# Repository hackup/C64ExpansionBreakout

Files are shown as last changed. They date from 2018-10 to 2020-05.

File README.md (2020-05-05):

# C64ExpansionBreakout

This is an adapter board for the [expansion port](https://www.c64-wiki.com/wiki/Expansion_Port) of the Commodore 64. It connects the expansion port to a standard 830 pin prototyping breadboard to assist with the development of modules or cartridges. **USE AT YOUR OWN RISK!**

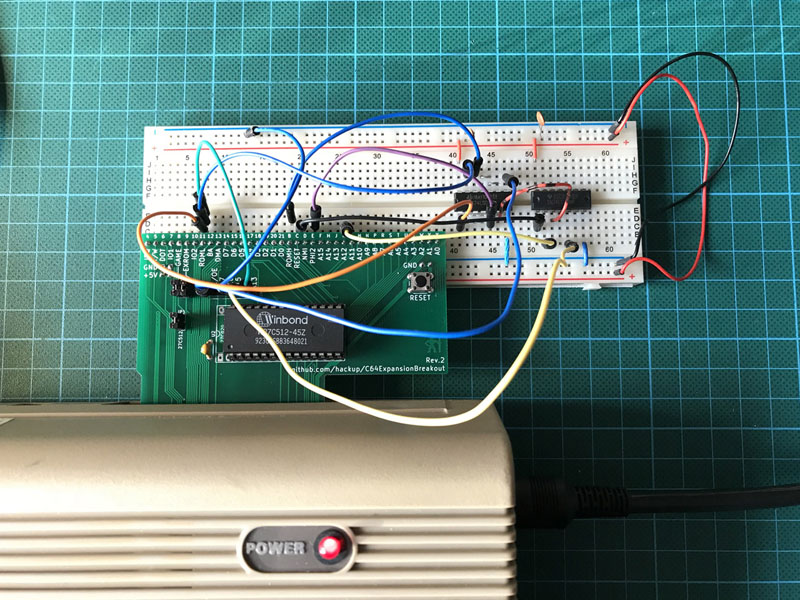
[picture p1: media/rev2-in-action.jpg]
Adapter In Action


### Revision 2
This revision adds an optional on-board slot for either a 27c512 or 27c020 EPROM. The data bus lines D0-D7 and the address bus lines A0-A12 are connected directly to the slot, as are GND and the 5V power rail. The remaining address bus lines of the EPROM and CE/OE are available on J4. Jumper JP1 must be closed if a 27c512 chip is used.

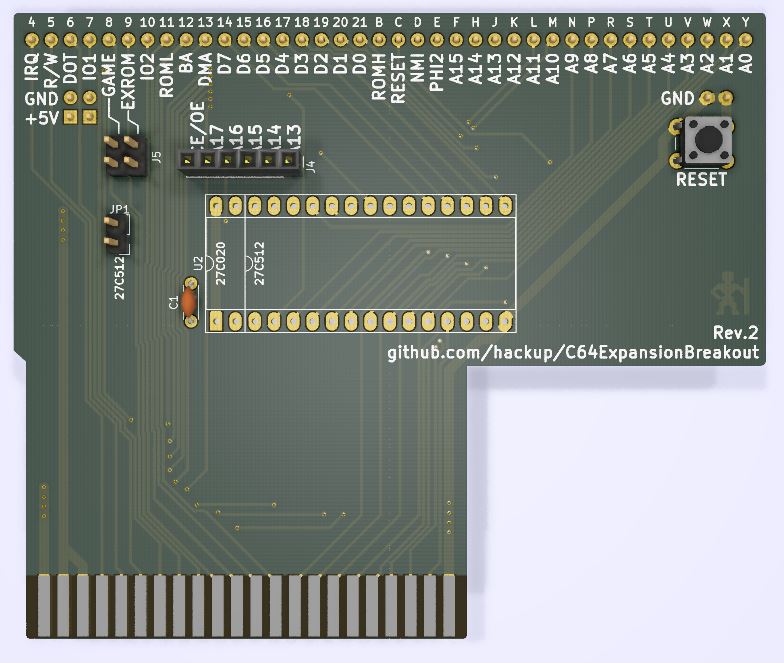
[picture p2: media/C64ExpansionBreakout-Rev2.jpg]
C64ExpansionBreakout Rev. 2


### Revision 1
The first revision directly connects all 38 lines from the expansion port tho the breadboard. 5V and GND are connected to the matching rails on the breadboard. A reset button is added for convenience.

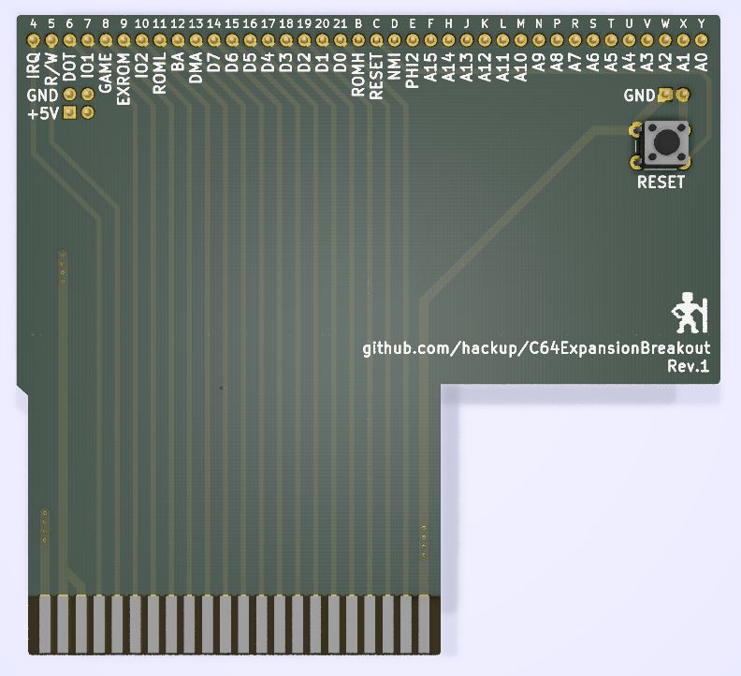
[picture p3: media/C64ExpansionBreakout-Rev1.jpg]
Pi1541io Rev.1


## License


This work is licensed under a
[Creative Commons Attribution-NonCommercial-ShareAlike 4.0 International License](http://creativecommons.org/licenses/by-nc-sa/4.0/).

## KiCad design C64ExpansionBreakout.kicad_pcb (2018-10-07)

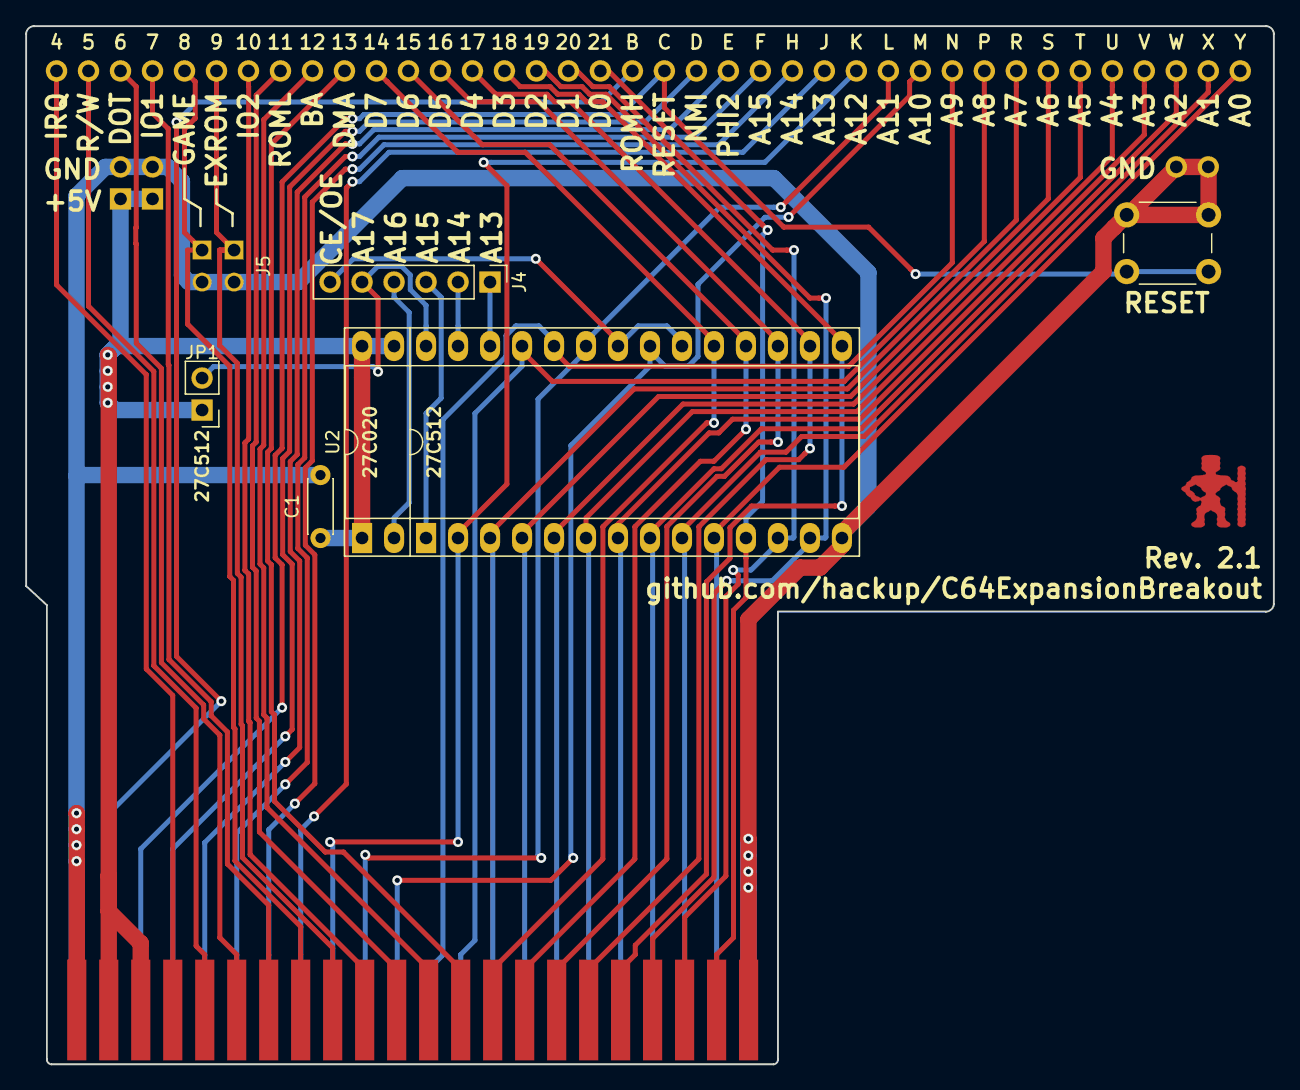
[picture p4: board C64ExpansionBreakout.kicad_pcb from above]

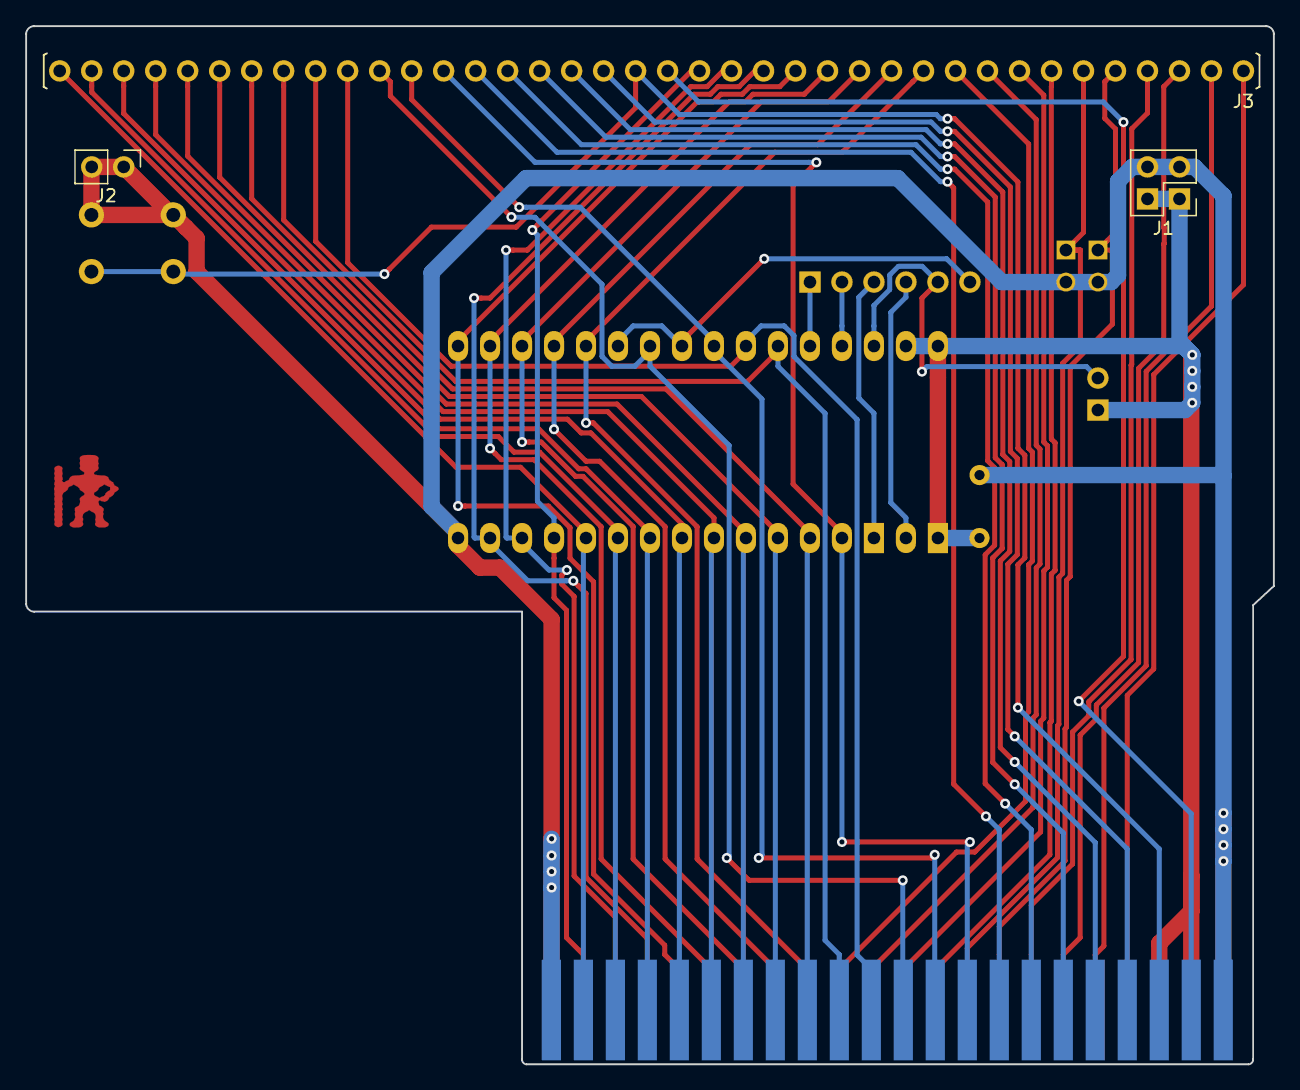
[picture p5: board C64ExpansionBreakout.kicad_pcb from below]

Board: 2 copper layers, 99.1 x 82.4 mm, 10 parts (3 on the bottom side), 46 nets.

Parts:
C1: 100n; C_Disc_D4.3mm_W1.9mm_P5.00mm
J1: Power; Pin_Header_Straight_2x02_Pitch2.54mm
J2: GND; Pin_Header_Straight_1x02_Pitch2.54mm
J3: Breakout; Pin_Header_Straight_1x38_Pitch2.54mm
J4: Other; Socket_Strip_Straight_1x06_Pitch2.54mm
J5: Config; Pin_Header_Straight_2x02_Pitch2.54mm
JP1: 27c512; Pin_Header_Straight_1x02_Pitch2.54mm
SW1: Reset; SW_PUSH_6mm
U1: C64-Exp-Port; C64-Cart-NoSilkS
U2: 27C512; DIP-32_W15.24mm_Socket_LongPads

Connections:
+5V: C1.1, J1.1, J1.2, JP1.1, U1.2, U1.3, U2.1, U2.31, U2.32
/CE: J4.6, U2.22, U2.24
/OA13: J4.1, U2.28
/OA14: J4.2, U2.29
/OA15: J4.3, U2.3
/OA16: J4.4, U2.2
/OA17: J4.5, JP1.2, U2.30
A0: J3.38, U1.Y, U2.12
A1: J3.37, U1.X, U2.11
A2: J3.36, U1.W, U2.10
A3: J3.35, U1.V, U2.9
A4: J3.34, U1.U, U2.8
A5: J3.33, U1.T, U2.7
A6: J3.32, U1.S, U2.6
A7: J3.31, U1.R, U2.5
A8: J3.30, U1.P, U2.27
A9: J3.29, U1.N, U2.26
A10: J3.28, U1.M, U2.23
A11: J3.27, U1.L, U2.25
A12: J3.26, U1.K, U2.4
A13: J3.25, U1.J
A14: J3.24, U1.H
A15: J3.23, U1.F
BA: J3.9, U1.12
D0: J3.18, U1.21, U2.13
D1: J3.17, U1.20, U2.14
D2: J3.16, U1.19, U2.15
D3: J3.15, U1.18, U2.17
D4: J3.14, U1.17, U2.18
D5: J3.13, U1.16, U2.19
D6: J3.12, U1.15, U2.20
D7: J3.11, U1.14, U2.21
DMA: J3.10, U1.13
DOT_CLK: J3.3, U1.6
EXROM: J3.6, J5.1, U1.9
GAME: J3.5, J5.3, U1.8
GND: C1.2, J1.3, J1.4, J2.1, J2.2, J5.2, J5.4, SW1.1, U1.1, U1.22, U1.A, U1.Z, U2.16
IO1: J3.4, U1.7
IO2: J3.7, U1.10
IRQ: J3.1, U1.4
NMI: J3.21, U1.D
PHI2: J3.22, U1.E
RESET: J3.20, SW1.2, U1.C
ROMH: J3.19, U1.B
ROML: J3.8, U1.11
RW: J3.2, U1.5

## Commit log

2018-04-10 Initial commit.
    [C64ExpansionBreakout.kicad_pcb, C64ExpansionBreakout.sch]
2018-04-10 Fine tuning.
    [C64ExpansionBreakout.kicad_pcb]
2018-06-29 Copied/rescued connector symbols.
    [C64ExpansionBreakout.sch]
2018-09-03 Updated page settings.
    [C64ExpansionBreakout.kicad_pcb, C64ExpansionBreakout.sch]
2018-09-06 Added 27C512 / 27C020 Eprom socket.
    [C64ExpansionBreakout.kicad_pcb, C64ExpansionBreakout.sch]
2018-09-07 Finalizing revision 2.
    [C64ExpansionBreakout.kicad_pcb, C64ExpansionBreakout.sch]
2018-09-30 Drill holes not wide enough for ZIF socket.
    [C64ExpansionBreakout.kicad_pcb]
2018-10-07 Revision update.
    [C64ExpansionBreakout.kicad_pcb]
2018-10-07 Mark pins 1 again.
    [C64ExpansionBreakout.kicad_pcb]
2018-10-07 Clean up libs.
    [C64ExpansionBreakout.kicad_pcb, C64ExpansionBreakout.sch]
2018-10-07 Added gerber files.
